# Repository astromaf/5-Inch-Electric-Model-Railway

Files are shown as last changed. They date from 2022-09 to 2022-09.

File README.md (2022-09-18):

# 5" Electric  Model Railway

Lovers of model railways have a wide collection of scales. One of the rarest are the 5-inch gauge. These machines are capable of taking several wagons full of visitors through an outdoor park. There are many different types, with steam being the most striking and representative.

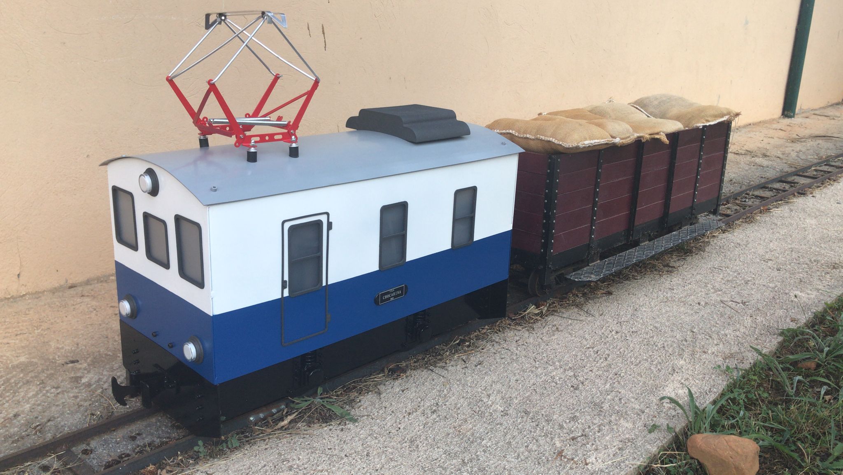
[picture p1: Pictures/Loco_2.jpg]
Chocarina Train


I like to build things, and in this repository I leave useful material on the construction of my first machine, a very simple electrical model. I have done this project with my father, who is the person who has passed on my love for trains.

Chocarina Train

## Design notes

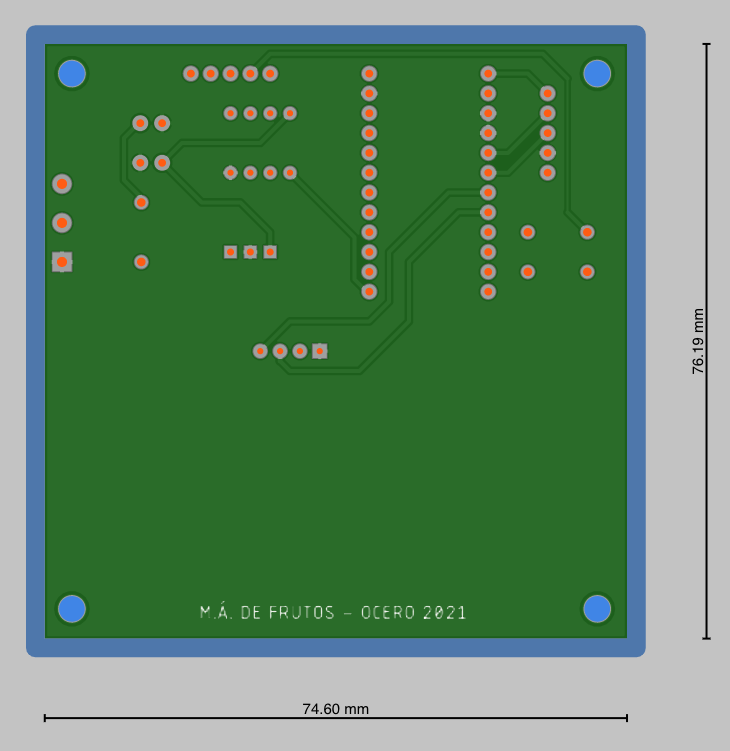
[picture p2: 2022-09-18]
Electronics/PCB_Render_BOT.png

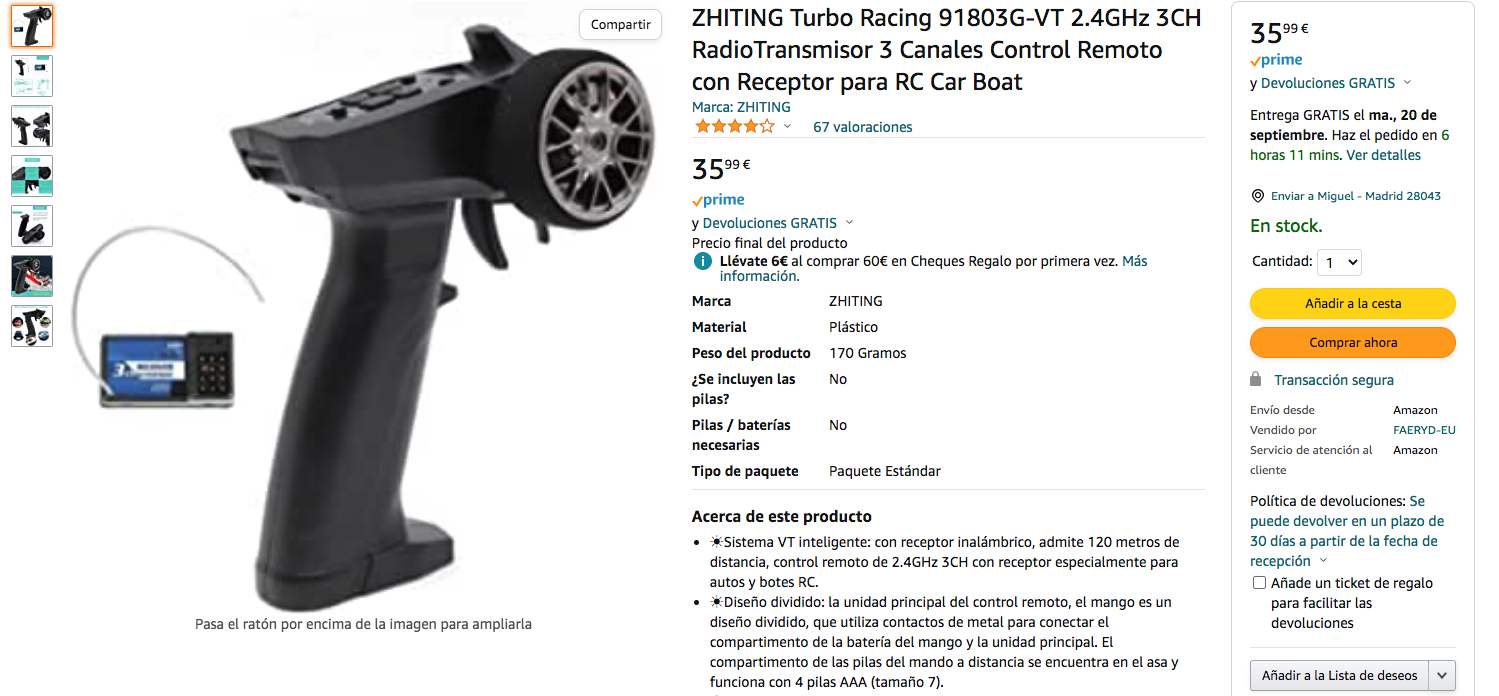
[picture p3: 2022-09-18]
Electronics/Remote_controller.png

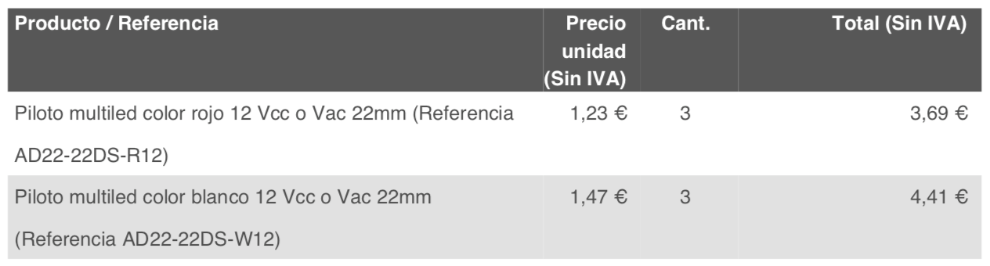
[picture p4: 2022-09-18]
Electronics/Light_Leds_ADAJUSA.png

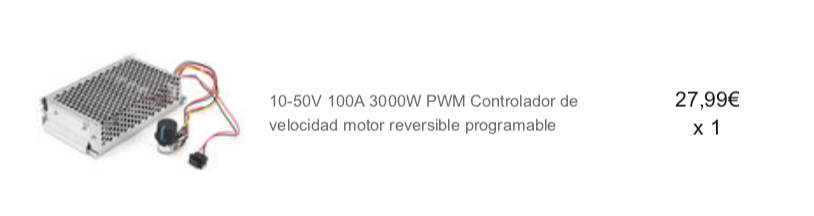
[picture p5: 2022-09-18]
Electronics/Motor_Driver.png

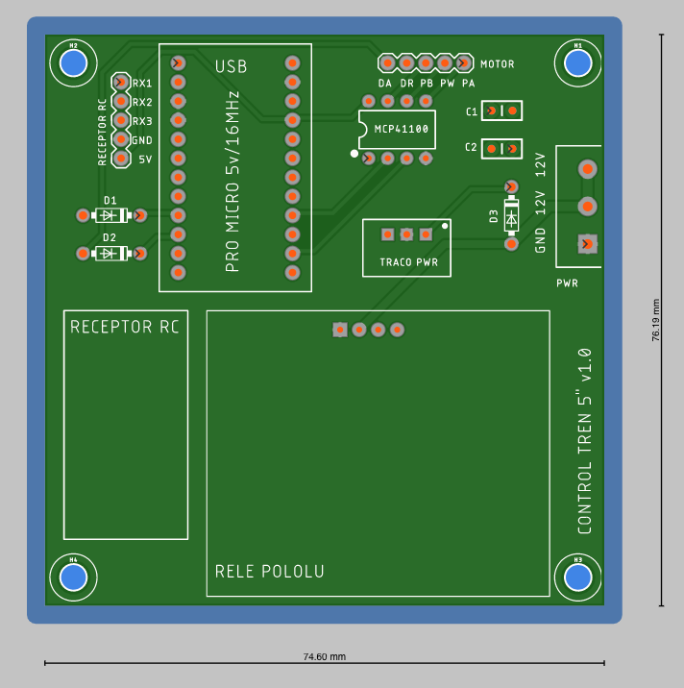
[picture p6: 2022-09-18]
Electronics/PCB_Render_TOP.png

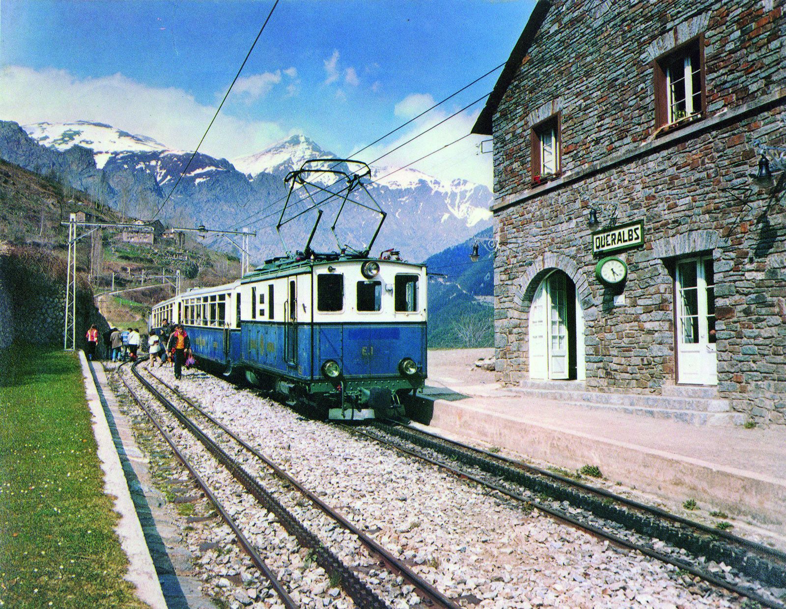
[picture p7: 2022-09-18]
Pictures/Tren_Nuria.jpeg

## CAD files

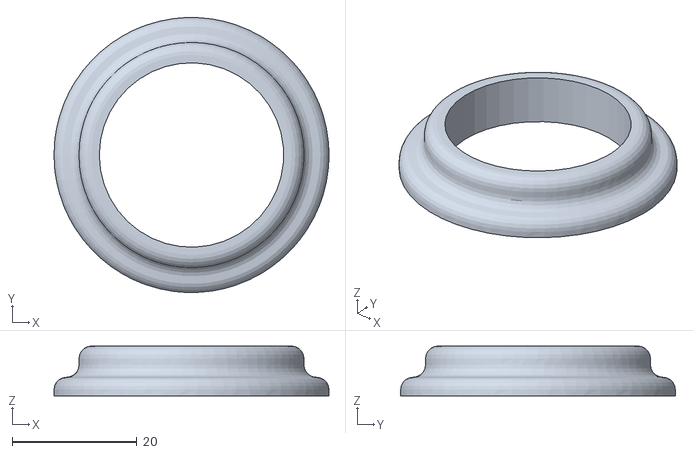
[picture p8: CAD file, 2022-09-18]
Body shell design/3D_Accesories/Light_Trim.stl
44.0 x 44.0 x 8.00

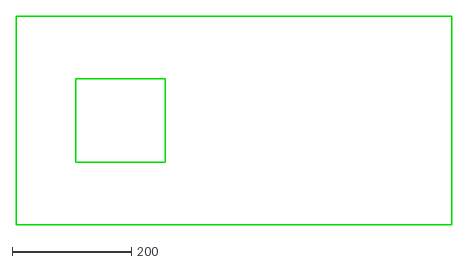
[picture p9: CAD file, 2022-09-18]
Body shell design/Roof.dxf
730.0 x 350.0

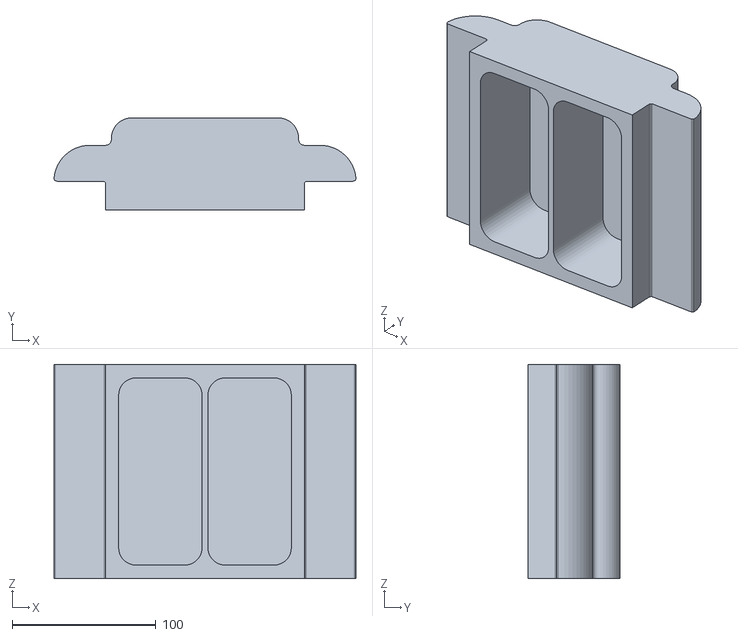
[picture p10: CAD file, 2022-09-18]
Body shell design/3D_Accesories/Air_Conditioner_mini_roof.stl
209.8 x 64.0 x 149.0

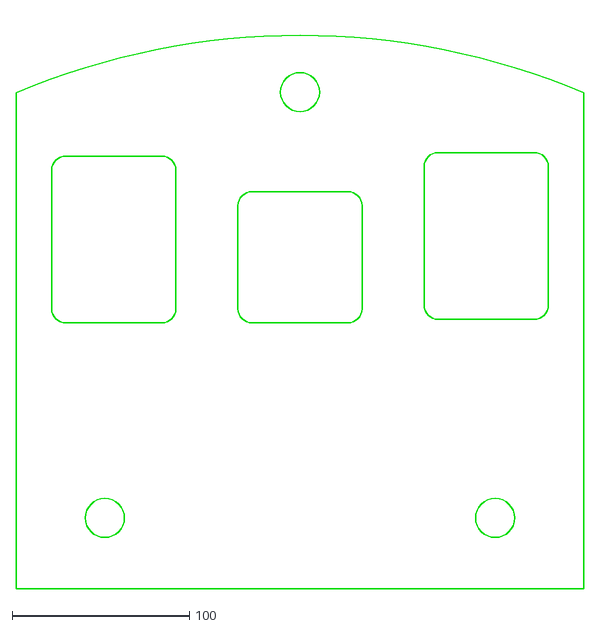
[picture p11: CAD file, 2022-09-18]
Body shell design/Frontal.dxf
320.0 x 322.9

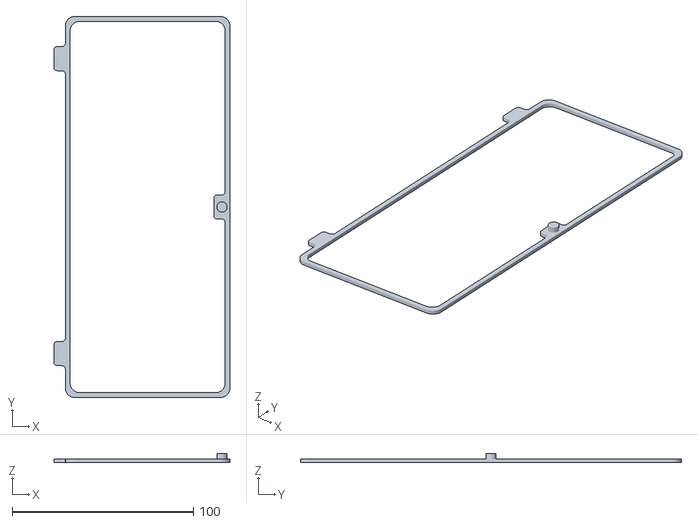
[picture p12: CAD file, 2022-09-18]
Body shell design/3D_Accesories/Door_frame.stl
97.2 x 210.4 x 5.00

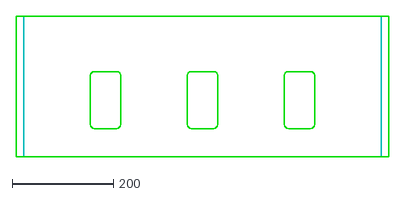
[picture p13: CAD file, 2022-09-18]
Body shell design/Lateral.dxf
737.7 x 279.0

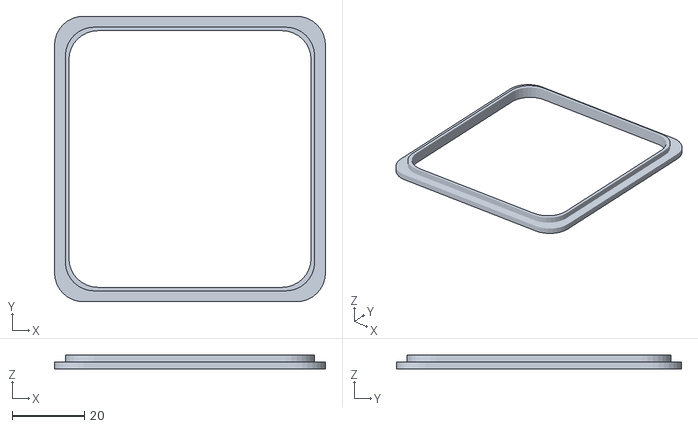
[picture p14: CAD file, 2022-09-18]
Body shell design/3D_Accesories/Small_Window_Frame.stl
75.0 x 79.0 x 4.00

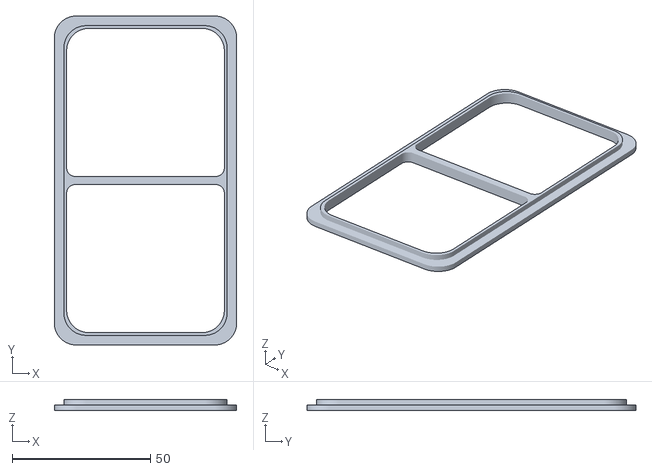
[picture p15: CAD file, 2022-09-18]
Body shell design/3D_Accesories/Lateral_Window_Frame.stl
66.0 x 119.0 x 4.00

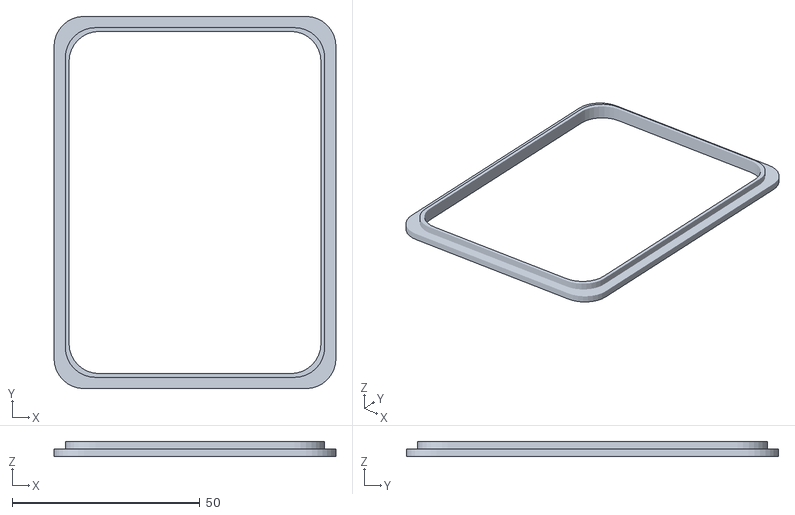
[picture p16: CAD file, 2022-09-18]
Body shell design/3D_Accesories/Big_Window_Frame.stl
75.0 x 99.0 x 4.00

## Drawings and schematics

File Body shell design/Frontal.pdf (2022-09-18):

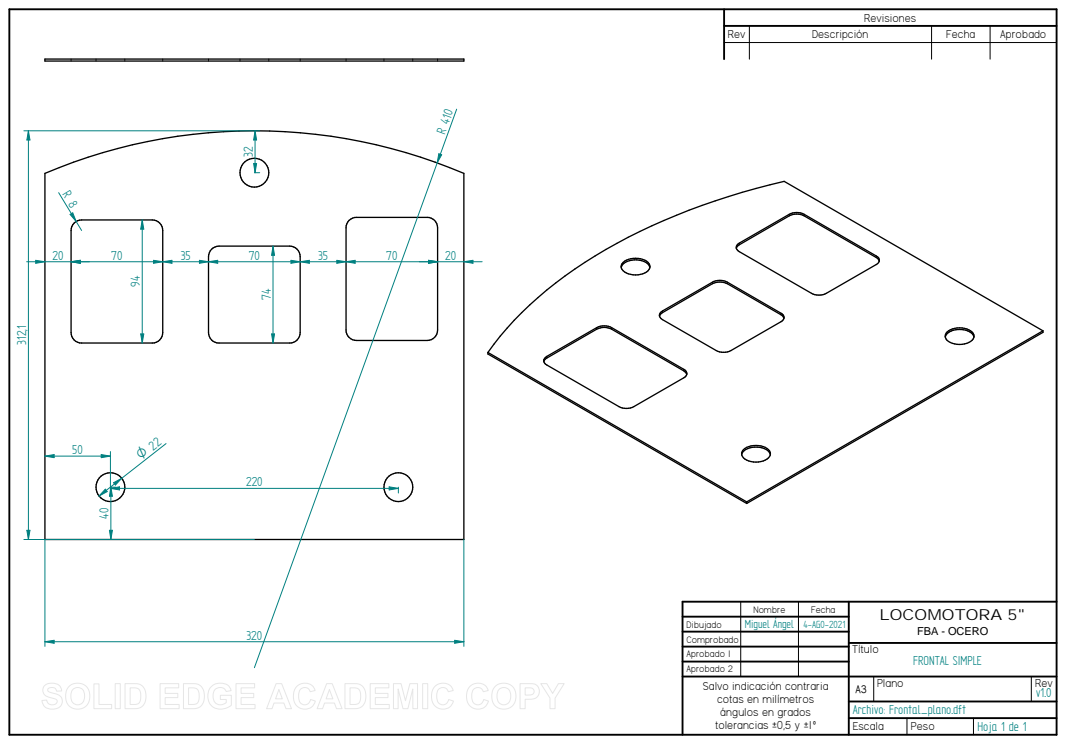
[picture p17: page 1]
Título; FRONTAL SIMPLE; Archivo: Frontal_plano.dft; Escala; Peso; Hoja 1 de 1

Revisiones

Rev | Descripción | Fecha | Aprobado

Nombre | Fecha | LOCOMOTORA 5" FBA - OCERO

Dibujado | Miguel Ángel | 4-AG0-2021
Comprobado
Aprobado 1
Aprobado 2
Salvo indicación contraria cotas en milímetros ángulos en grados tolerancias ±0,5 y ±1º | A3 | Plano | Rev v1.0

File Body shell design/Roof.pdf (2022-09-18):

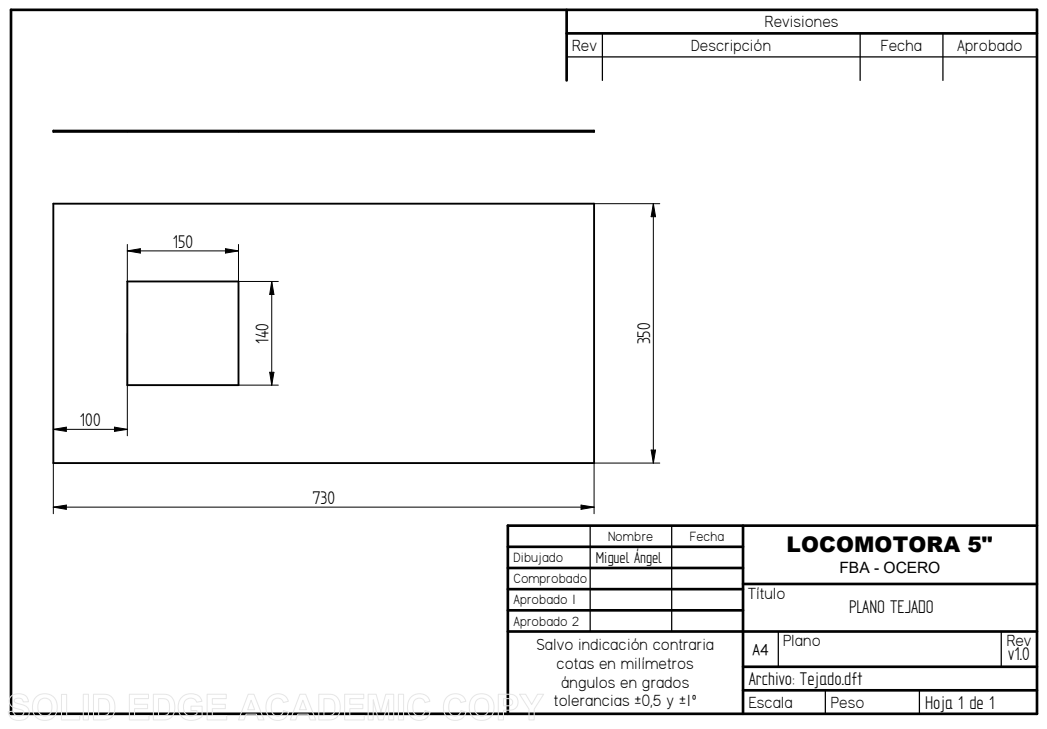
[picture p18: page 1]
Título; PLANO TEJADO; Escala; Peso; Hoja 1 de 1; 730 ¹⁴⁰

Revisiones

Rev | Descripción | Fecha | Aprobado

Nombre | Fecha | LOCOMOTORA 5" FBA - OCERO

Dibujado | Miguel Ángel
Comprobado
Aprobado 1
Aprobado 2
Salvo indicación contraria cotas en milímetros ángulos en grados tolerancias ±0,5 y ±1º | A4 | Plano | Rev v1.0

Archivo: Tejado.dft

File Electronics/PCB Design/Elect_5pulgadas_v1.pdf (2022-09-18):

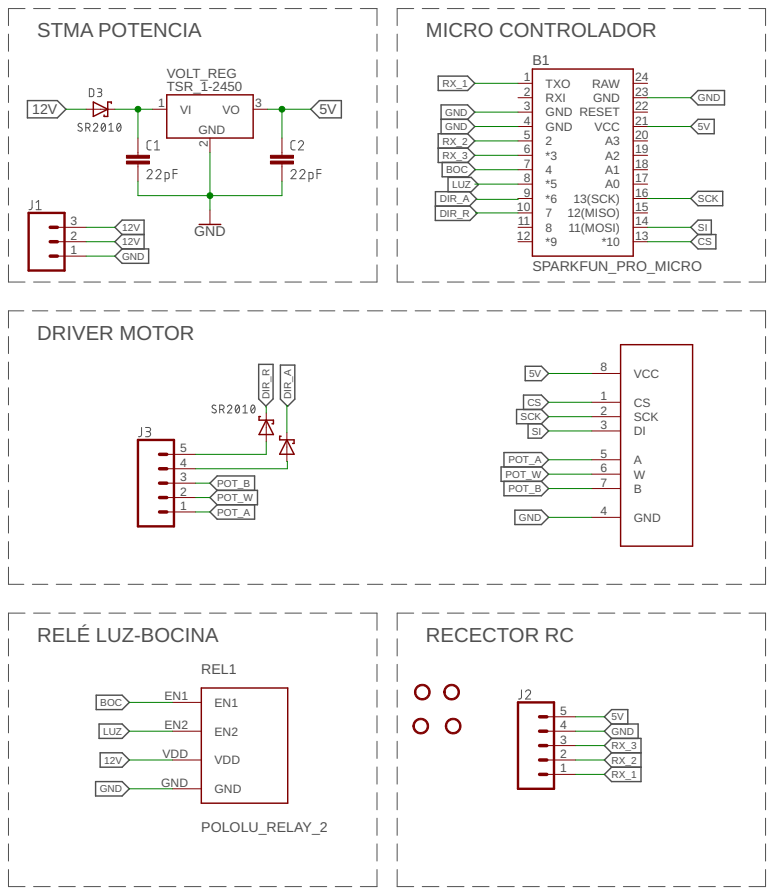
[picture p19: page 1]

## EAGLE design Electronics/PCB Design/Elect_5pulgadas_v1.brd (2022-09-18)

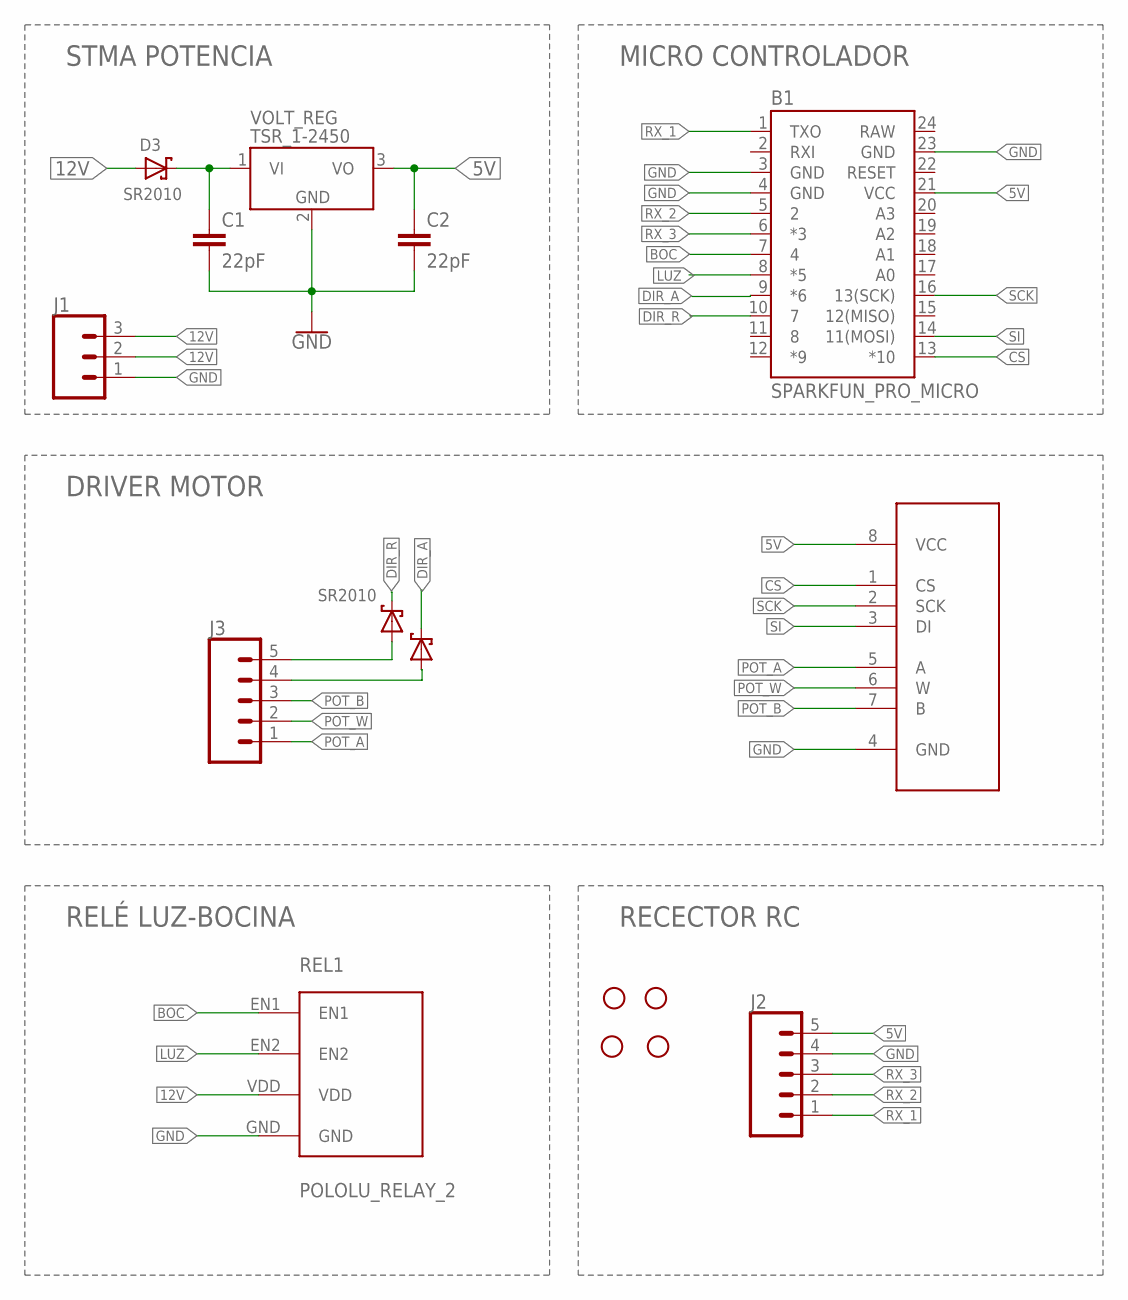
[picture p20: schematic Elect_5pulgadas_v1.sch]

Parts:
B1: SPARKFUN_PRO_MICRO
C1, C2: 22pF; CAP-PTH-SMALL-KIT
D1, D2, D3: SR2010; DO41-7.6
H1, H2, H3, H4: STAND-OFF
J1: CONN_03-SCREW-5MM; SCREWTERMINAL-5MM-3
J2, J3: CONN_05; 1X05
REL1: POLOLU_RELAY_2
U1: MCP41XXX; DIP08
VOLT_REG: TSR_1-2450; TSR-1

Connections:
5V: B1.21 (VCC), C2.1, J2.5, U1.8 (VCC), VOLT_REG.3 (VO)
12V: D3.A, J1.2, J1.3, REL1.VDD
BOC: B1.7 (4), REL1.EN1
CS: B1.13 (*10), U1.1 (CS)
DIR_A: B1.9 (*6), D1.C
DIR_R: B1.10 (7), D2.C
GND: B1.3 (GND), B1.4 (GND), B1.23 (GND), C1.2, C2.2, J1.1, J2.4, REL1.GND, U1.4 (GND), VOLT_REG.2 (GND)
LUZ: B1.8 (*5), REL1.EN2
unnamed: D1.A, J3.4
unnamed: D2.A, J3.5
POT_A: J3.1, U1.5 (A)
POT_B: J3.3, U1.7 (B)
POT_W: J3.2, U1.6 (W)
RAW: B1.24 (RAW)
RX_1: B1.1 (TXO), J2.1
RX_2: B1.5 (2), J2.2
RX_3: B1.6 (*3), J2.3
SCK: B1.16 (13(SCK)), U1.2 (SCK)
SI: B1.14 (11(MOSI)), U1.3 (DI)
VI: C1.1, D3.C, VOLT_REG.1 (VI)

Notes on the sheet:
STMA POTENCIA
RELÉ LUZ-BOCINA
DRIVER MOTOR
RECECTOR RC
MICRO CONTROLADOR

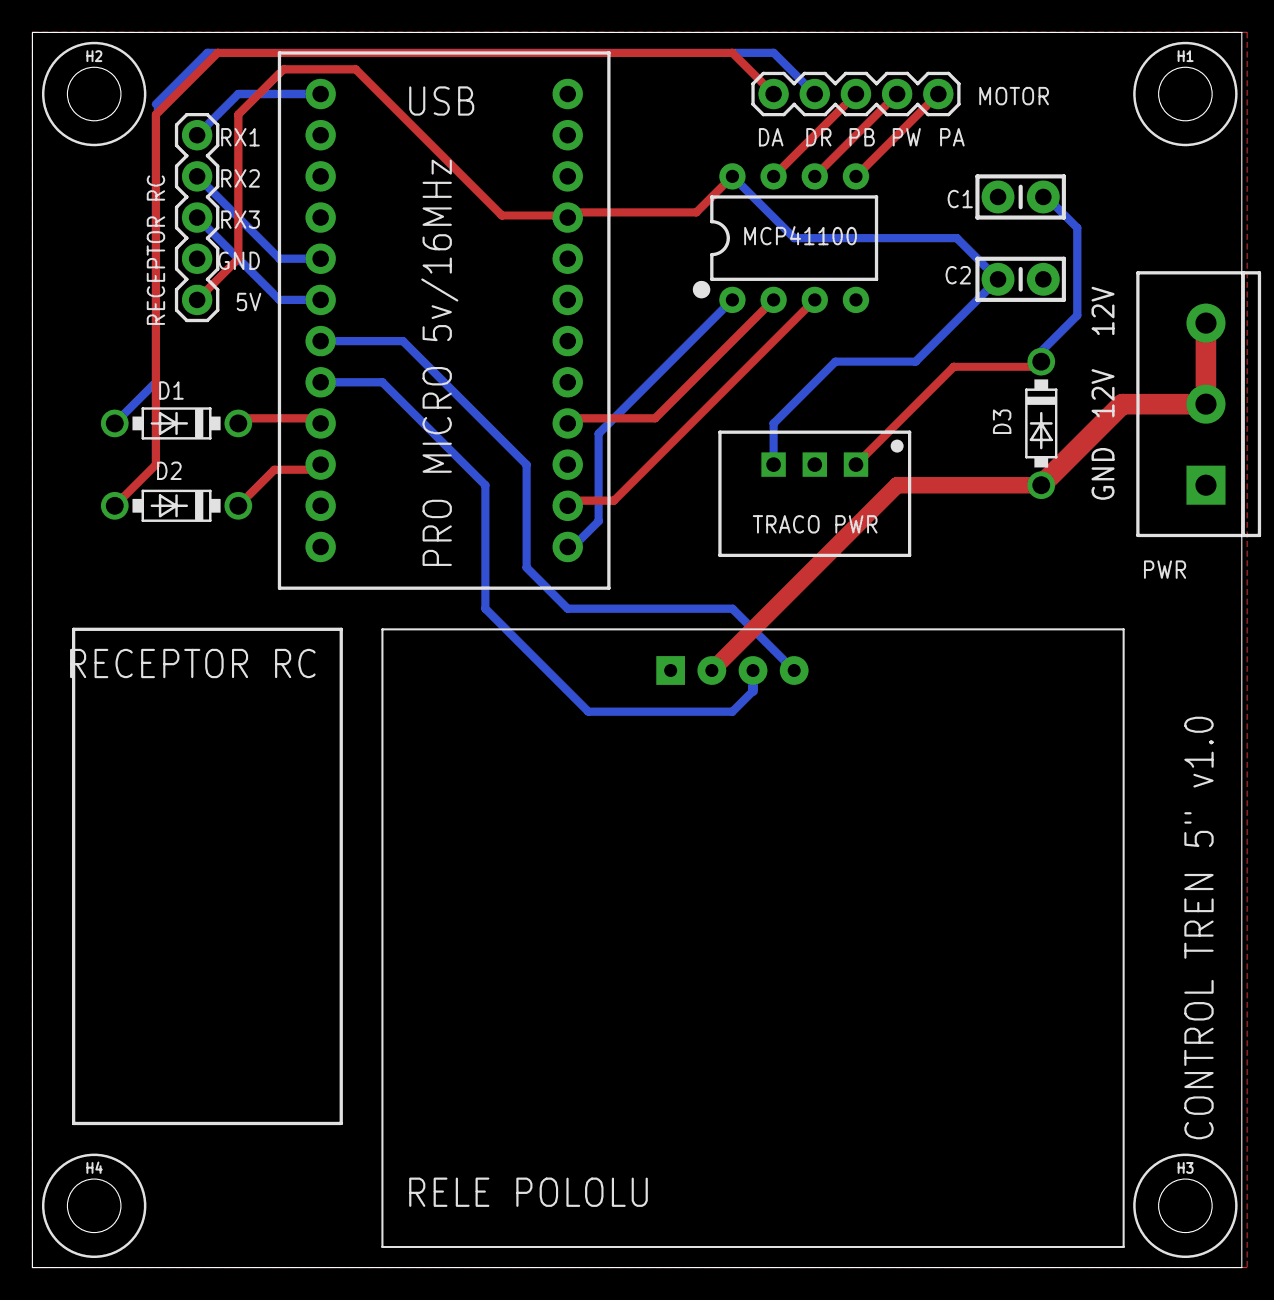
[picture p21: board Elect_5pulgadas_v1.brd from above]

Board: 2 copper layers, 74.6 x 76.2 mm, 16 parts (0 on the bottom side), 19 nets.

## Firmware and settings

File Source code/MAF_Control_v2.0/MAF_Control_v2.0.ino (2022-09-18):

#include "main.h"
boolean _TEST = 0;
/// Frecuencia Ejecución Bucle Loop
const float freq_ciclo = 20;  //En Hz
const float t_espera =  (1.0 / freq_ciclo) * 1000;
long _loop_timer;

void setup() {
  init_Interrupts();
  init_DigiPot();
  init_Funciones();
  Serial.begin(115200);
  delay(1000);
  wellcome_terminal();
  //testDigiPOT();
}

void loop() {
  while (millis() - _loop_timer < t_espera);
  _loop_timer = millis();
  manageComms();
  
  if (!_CalibrationMode) {
    lee_Controles(ch1_Pulse, ch2_Pulse, ch3_Pulse);
    revision_seguridad(ch3_Pulse);
    ejecuta_Acciones();
  }
  else {
    modo_calibracion(ch1_Pulse);
  }
  print_Samples();
}

////////////Pint-SAMPLES////////////
void print_Samples() {
   if (false){ 
    Serial.print("CH1:");
    Serial.print(ch1_Pulse);
    Serial.print("\t");
    Serial.print("Med:");
    Serial.print(_MedRC);
    Serial.print("\t");
    Serial.print("Pot:");
    Serial.print(_potencia);
    Serial.println("\t");
   }


  
  if (_ECO){ 
    Serial.print("CH1:");
    Serial.print(ch1_Pulse);
    Serial.print("\t");
    Serial.print("CH2:");
    Serial.print(ch2_Pulse);
    Serial.print("\t");
    Serial.print("CH3:");
    Serial.print(ch3_Pulse + 100);
    Serial.print("\t");
    Serial.print("Dir:");
    Serial.print(_dir);
    Serial.print("\t");
    Serial.print("Pot:");
    Serial.print(_potencia);
    Serial.print("\t");
    Serial.print("Pes:");
    Serial.print(_bloqueo);
    Serial.print("\t");
    Serial.print("Boz:");
    Serial.print(_bocina);
    Serial.print("\t");
    Serial.print("Luz:");
    Serial.print(_luz);
    Serial.print("\t");
    Serial.print("SAFE:");
    Serial.print(_SafeMode);
    Serial.print("\t");
    Serial.print("\t");
    Serial.print("MAX_NVM:");
    Serial.print(_MaxRC);
    Serial.print("\t");
    Serial.print("MIN_NVM:");
    Serial.print(_MinRC);
    Serial.print("\t");
    Serial.print("MED_NVM:");
    Serial.print(_MedRC);
    Serial.println("\t");
  }
}

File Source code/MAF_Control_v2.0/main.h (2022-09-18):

#include <SPI.h>
#include <EEPROM.h>
#include "interrupts.h"

//////HARDWARE//////
//RC-Channel
const byte channel_1_Pin = 1; //Volante->Potencia
const byte channel_2_Pin = 2; //Gatillo->Bocina
const byte channel_3_Pin = 3; //Interruptor->Luz

//Equipos
const byte rele_Bocina = 4;
const byte rele_Luz =5;
const byte pin_Avanza = 6;
const byte pin_Retrocede = 7;

//SPI
/*
  MCP41100
  CS >>> D10
  SCLK >> D15
  MOSI/DI >> D16
*/
const byte CS = 10;
byte spi_address = 0x11;



//////GLOBAL VARIABES//////
float _potencia = 0; //0-255
boolean _dir = 0;
boolean _bocina = 0;
boolean _luz = 0;
boolean _bloqueo = 0;
boolean _SafeMode = 0;
boolean _CalibrationMode= 0;
boolean _ECO=0;
boolean _cal_p_vez=true;
int _MaxRC=2000;
int _MinRC=1000;
int _MedRC=12;

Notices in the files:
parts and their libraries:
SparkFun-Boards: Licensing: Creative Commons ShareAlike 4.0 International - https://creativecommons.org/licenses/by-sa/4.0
